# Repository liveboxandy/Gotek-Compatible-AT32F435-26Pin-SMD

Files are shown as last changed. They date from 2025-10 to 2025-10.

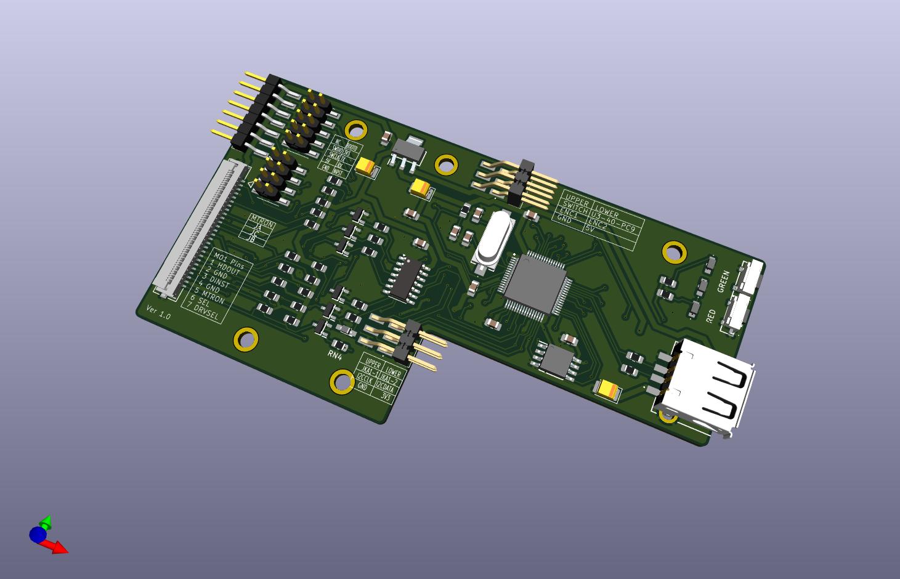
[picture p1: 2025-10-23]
Gotek.jpg

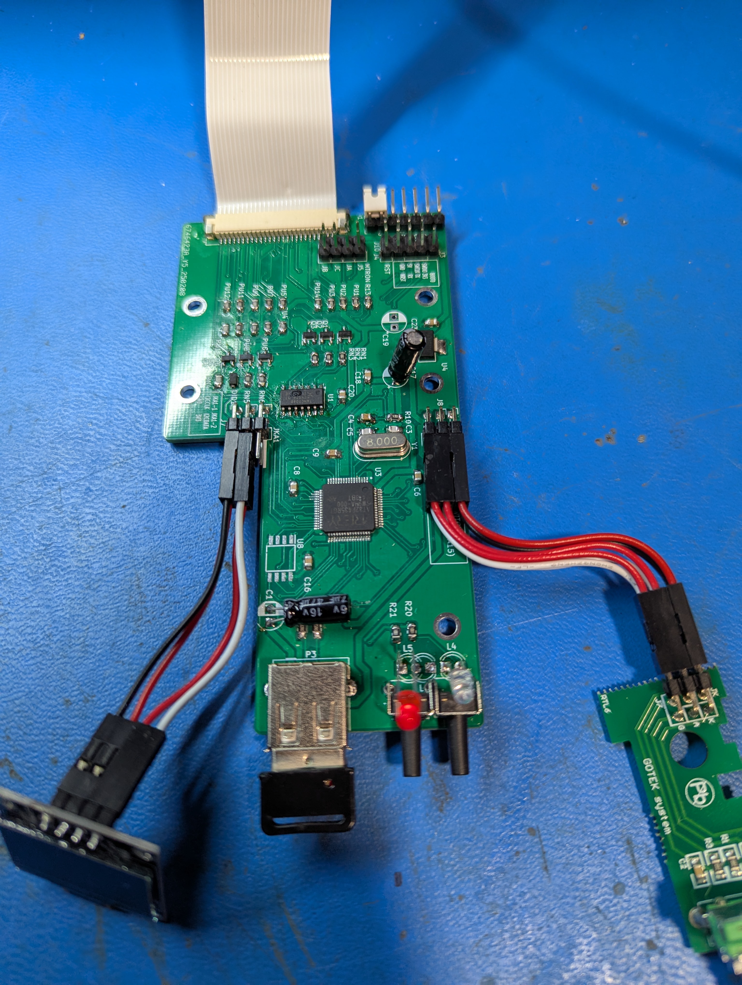
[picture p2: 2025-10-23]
Pictures/AT32F435RGT7.jpg

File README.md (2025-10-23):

Initial schematic and gerbers for a Gotek(?) compatible with an Artery AT32F435RGT7 chip and a 26 Pin FFC connector using SMD components.

Used SFRKC30.AT4.35 PCB for most of the schematic and layout but used SFRC2D.B PCB for the 26 Pin FFC connections.

Used photographs and a multimeter along with removing U1 and U3 on the SFRKC30.AT4.35 to get to the traces underneath.

Where possible I followed the original PCB routing of the SFRKC30.AT4.35 but Kicad has some different rules for trace widths (between pins 5&6 of U8, which isn't fitted for FlashFloppy).

Using SMD components required a few more routing changes but electrically it is still good. What a pain in the ass to find SMD parts that don't cost a fortune and have Kicad mod and sym files.

Restructured folders

Added all non pop components so that ibom displays everthing

Added ibon (bom.ibom.html)

U8 not fitted for use with FlashFloppy.

LEDS 3 & 5 are not normally fitted

Works as a replacement for the floppy in a TDS3052 Oscilloscope. Just needs a very slim case (13mm)

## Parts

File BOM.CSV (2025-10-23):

Reference | Value | Datasheet | Footprint | Qty | DNP
C1,C17,C19 | 47uF | ~ | Capacitor_Tantalum_SMD:CP_EIA-3528-21_Kemet-B_Pad1.50x2.35mm_HandSolder | 3
C3,C5 | 22pF | ~ | Capacitor_SMD:C_0805_2012Metric_Pad1.18x1.45mm_HandSolder | 2
C4,C6,C8,C9,C16,C18,C20,C23 | 100nF | ~ | Capacitor_SMD:C_0805_2012Metric_Pad1.18x1.45mm_HandSolder | 8
DID1 | 1N4148WS | https://www.vishay.com/docs/85751/1n4148ws.pdf | Gotek:SODFL2512X90N | 1
J1 | TSM-107-01-L-SH | http://suddendocs.samtec.com/prints/tsm-1xx-xx-xxx-xx-x-xxx-x-mkt.pdf | Gotek:TSM-107-01-L-SH | 1
J4 | TSM-105-04-S-DV | https://componentsearchengine.com/Datasheets/1/TSM-105-04-S-DV.pdf | Gotek:TSM-105-04-S-DV | 1
J5 | TSM-104-04-S-DV | http://suddendocs.samtec.com/prints/tsm-1xx-xx-xxx-xx-x-xxx-x-mkt.pdf | Gotek:TSM-104-04-S-DV | 1
J7,J8 | TSM-103-01-L-DH-TR | http://suddendocs.samtec.com/prints/tsm-1xx-xx-xxx-xx-xx-xxx-xx-mkt1.pdf | Gotek:TSM-103-01-L-DH-TR | 2
L3,L4 | LED GREEN | ~ | Gotek:APT2012PGW | 2
L5 | LED RED | https://docs.broadcom.com/doc/AV02-0975EN | Gotek:HSMCC177 | 1
P1 | 2005280260 | 2005280260 | Gotek:MOLEX_CON_2005280260 | 1
P3 | USB_A | https://gct.co/files/drawings/usb1046.pdf?v=ccb5d20d-0631-4297-aa3c-9c34fccf9fbc | Gotek:USB1046GF0190LBA | 1
PU1,PU2,PU3,PU4,PU5,PU6,PU7,PU8,PU9,PU10,PU11,PU12,PU13,PU14,R20,RN1,RN2,RN3,RN4,RN5,RN6 | 1K | ~ | Resistor_SMD:R_0805_2012Metric_Pad1.20x1.40mm_HandSolder | 21
Q1,Q2,Q3,Q4,Q5,Q6 | PMBT2222A,215 | https://assets.nexperia.com/documents/data-sheet/PMBT2222A.pdf | Gotek:SOT95P280X130-3N | 6
R1,R2 | 22R | ~ | Resistor_SMD:R_0805_2012Metric_Pad1.20x1.40mm_HandSolder | 2
R10,R13 | 4K7 | ~ | Resistor_SMD:R_0805_2012Metric_Pad1.20x1.40mm_HandSolder | 2
R21 | 12K | ~ | Resistor_SMD:R_0805_2012Metric_Pad1.20x1.40mm_HandSolder | 1
S3,S4 | 1188E-1K2-V-T_R | http://www.dip.com.tw/en/en-product-information/en-switch004/item/2445-1188?highlight=WzExODhd | Gotek:1188E1K2VTR | 2
U1 | 74AHC04 | https://assets.nexperia.com/documents/data-sheet/74AHC_AHCT04.pdf | Package_SO:SO-14_3.9x8.65mm_P1.27mm | 1
U3 | AT32F435RGT7 |  | Gotek:QFP50P1200X1200X160-64N | 1
U4 | AMS1117-3.3 | http://www.advanced-monolithic.com/pdf/ds1117.pdf | Gotek:SOT229P700X180-4N | 1
U8 | SST25VF016B-50-4C-S2AF | https://ww1.microchip.com/downloads/en/DeviceDoc/20005044C.pdf | Gotek:SOIC127P790X216-8N | 1
Y1 | 8Mhz | https://componentsearchengine.com/Datasheets/1/LFXTAL050985Bulk.pdf | Gotek:LFXTAL050985Bulk | 1

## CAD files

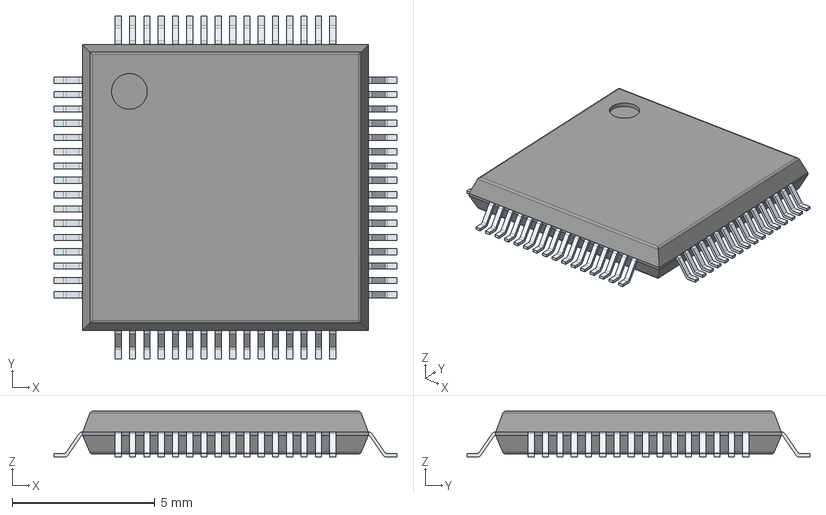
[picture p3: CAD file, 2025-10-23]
STP/AT32F415RxT7.stp
12.0 x 12.0 x 1.60 mm
PinsArrayLR
PinsArrayTB

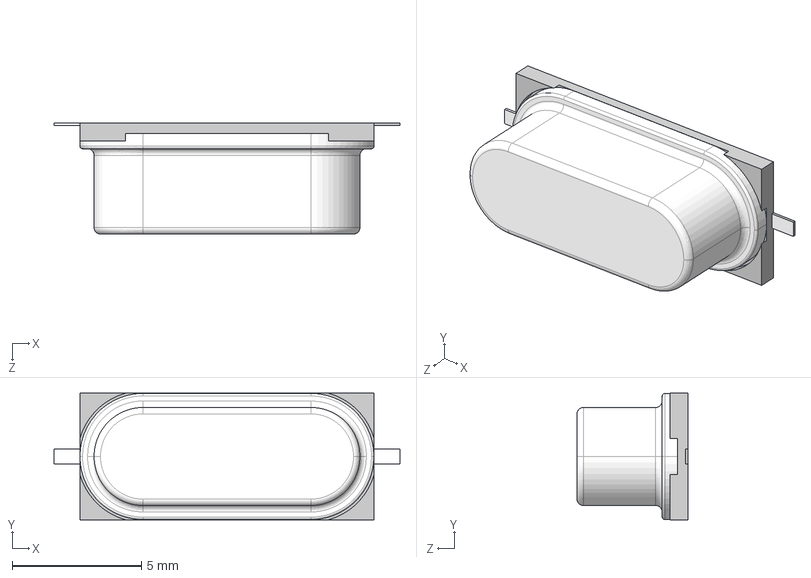
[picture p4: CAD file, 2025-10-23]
STP/LFXTAL050985Bulk.stp
13.4 x 4.90 x 4.30 mm

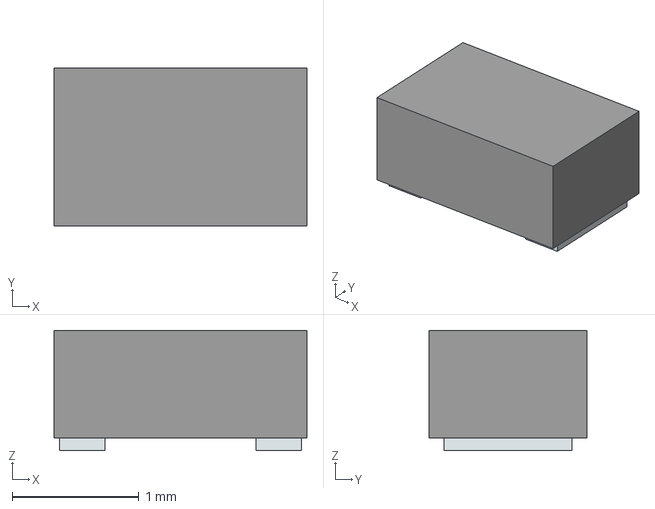
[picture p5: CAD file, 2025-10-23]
STP/APT2012PGW.stp
2.00 x 1.25 x 0.95 mm
Pins

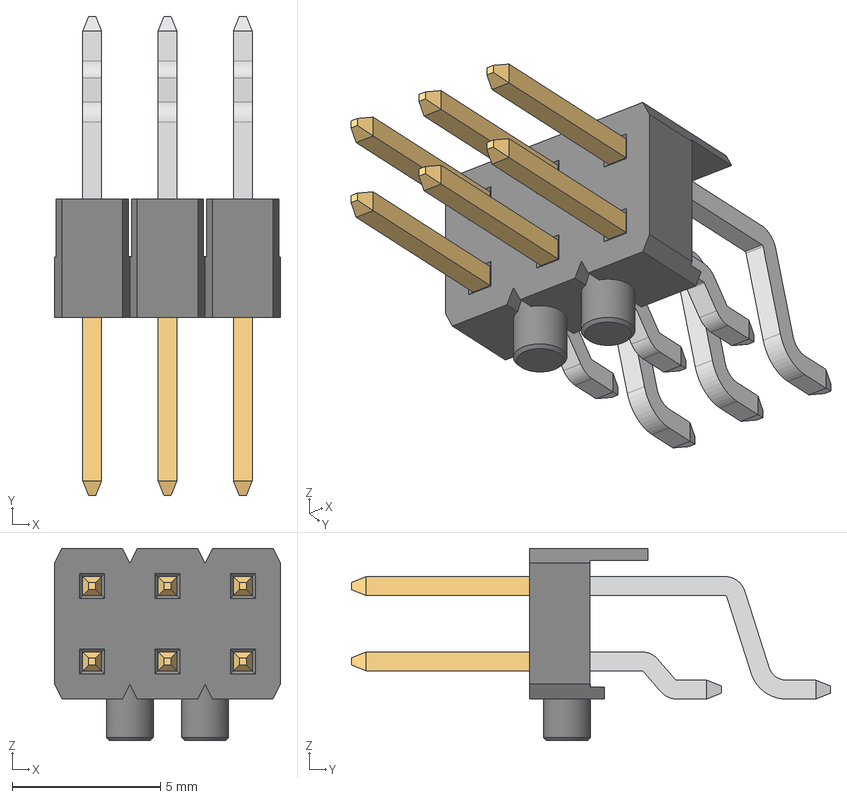
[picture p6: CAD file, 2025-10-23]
STP/6101XX249121_610106249121.step
7.62 x 16.2 x 6.48 mm
6100xx249121_PIN LONGUE x 3
6100xx249121_PIN COURTE x 3

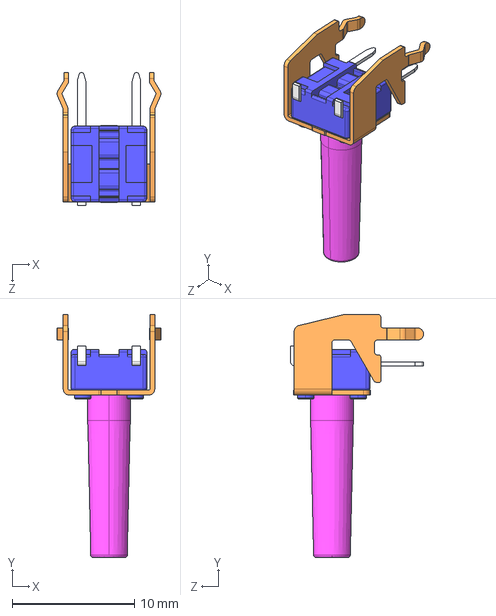
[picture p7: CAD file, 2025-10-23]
STP/SKHHNH.stp
8.50 x 19.9 x 10.9 mm

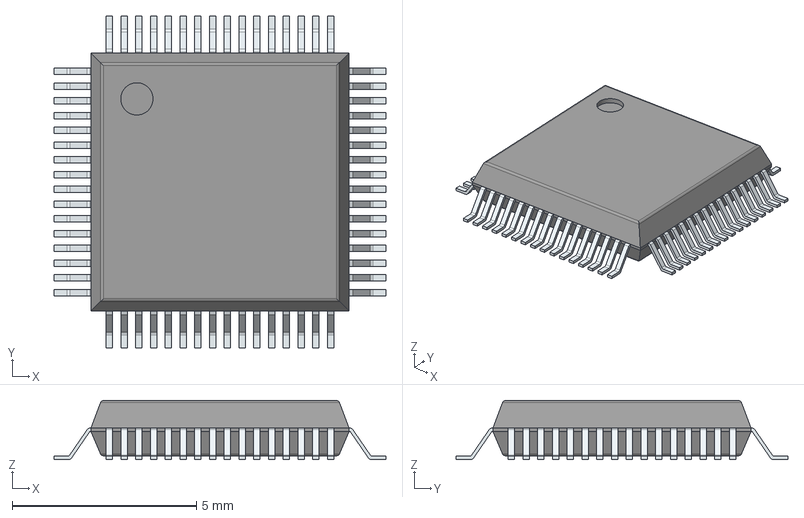
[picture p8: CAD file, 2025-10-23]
STP/at32f415rct7.stp
9.00 x 9.00 x 1.60 mm
PinsArrayLR
PinsArrayTB

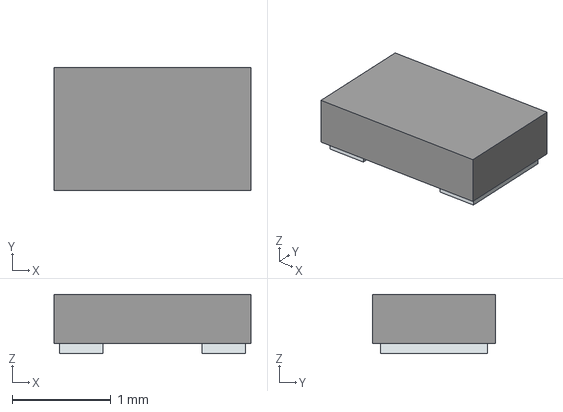
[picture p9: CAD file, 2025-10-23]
STP/HSMC-C177.stp
2.00 x 1.25 x 0.6 mm
Pins

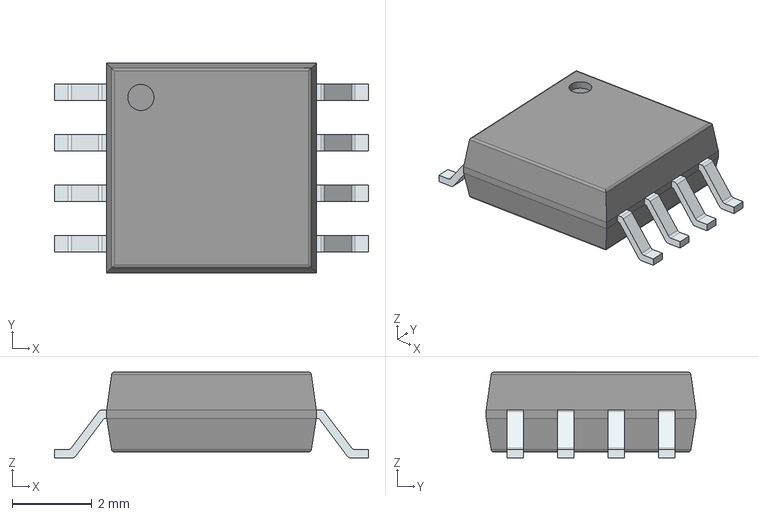
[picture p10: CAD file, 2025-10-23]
STP/SST25VF016B-50-4C-S2AF.stp
7.90 x 5.28 x 2.16 mm
PinsArrayLR

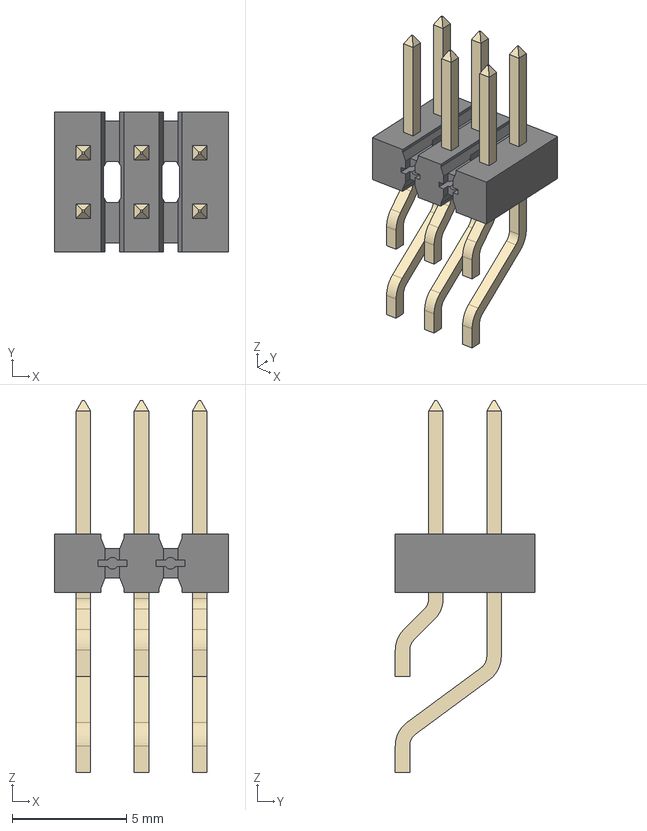
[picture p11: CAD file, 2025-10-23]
STP/TSM-103-01-L-DH-TR.stp
7.62 x 6.10 x 16.3 mm

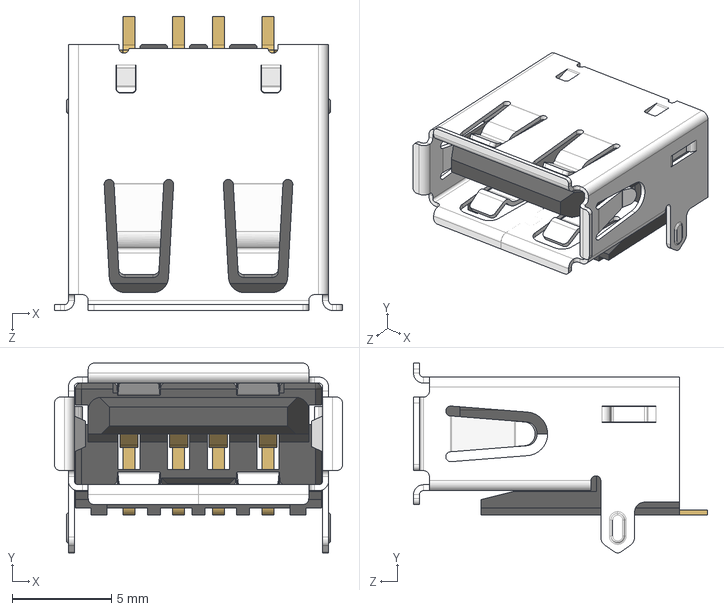
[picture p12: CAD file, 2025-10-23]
STP/USB1046-GF-0190-L-B-A.stp
14.5 x 9.55 x 14.8 mm

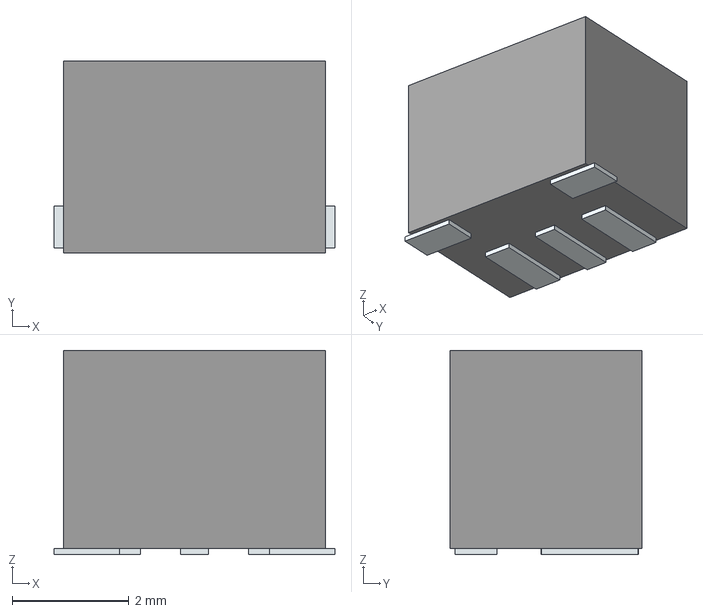
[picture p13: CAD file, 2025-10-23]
STP/SKRTLBE010.stp
4.82 x 3.30 x 3.50 mm
Pins

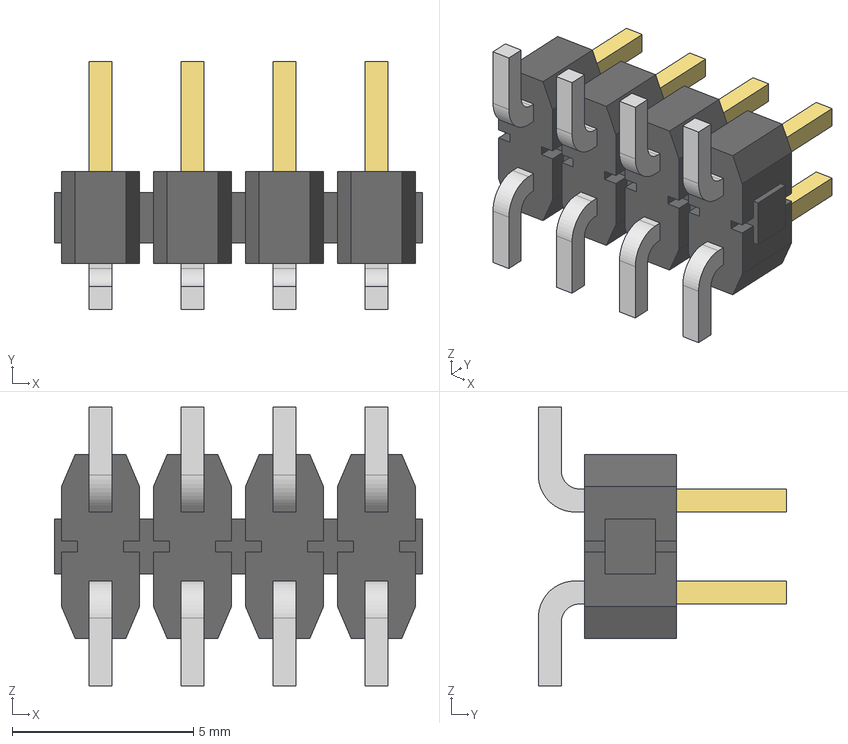
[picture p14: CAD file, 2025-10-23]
STP/TSM-104-04-S-DV.stp
10.2 x 6.86 x 7.70 mm
TSM-104-04-DV_body
T-1S6-21-S(-04-4-DV)
T-1S6-21-S(-04-4-DV)2

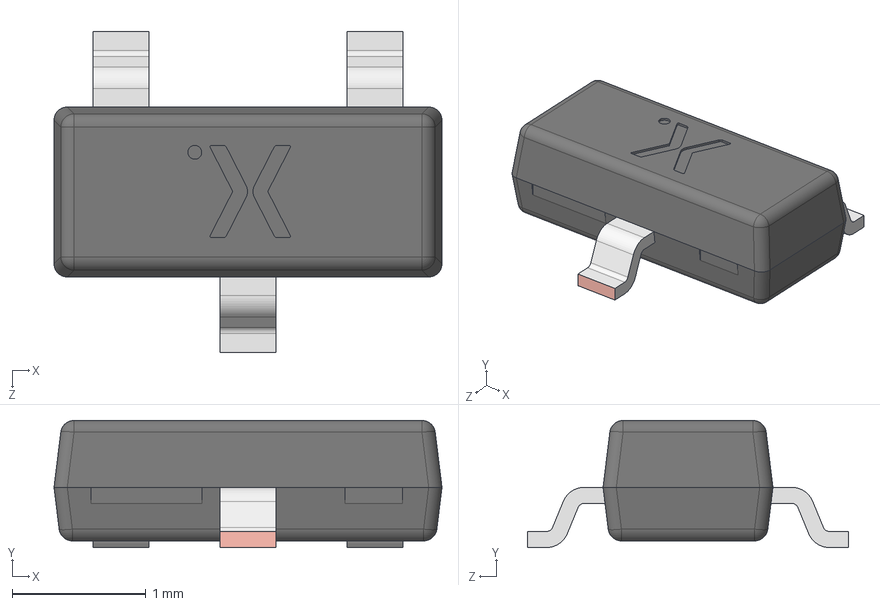
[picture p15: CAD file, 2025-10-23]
STP/PMBT2222A,215.stp
2.90 x 0.95 x 2.40 mm
SOT23 lower body
SOT23 Lead x 3
SOT23 Upper body

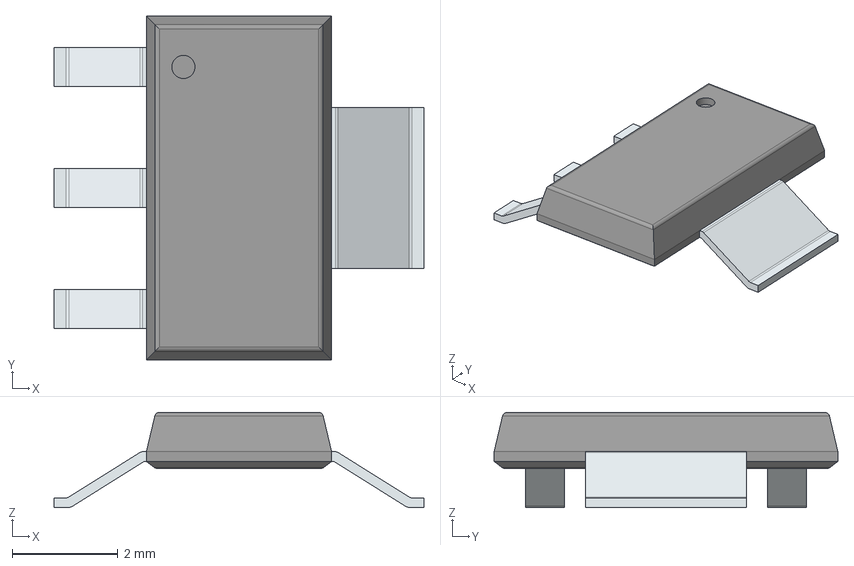
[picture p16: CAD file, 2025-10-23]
STP/ams1117-3.3v.stp
7.00 x 6.50 x 1.80 mm
PinsArrayL
FilletPinR

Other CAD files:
STP/SKHHNK.STEP
STP/SKHHNHA010.stp
STP/1188E-1K2-V-T_R.stp
STP/171826-4.stp
STP/1N4148WS.stp
STP/ABL-8.000MHZ-B2.stp
STP/M20-8750442.stp
STP/M20-8760442P.stp
STP/M20-8760542P.stp
STP/M20-8890245R.stp
STP/M20-8890345R.stp
STP/M20-8900705.stp
STP/Molex 2005280260.stp
STP/SKHHNK.stp
STP/SKRTLAE010.stp
STP/TSM-105-04-S-DV.stp
STP/TSM-107-01-L-SH.stp
STP/USB1055-GF-L-A.stp

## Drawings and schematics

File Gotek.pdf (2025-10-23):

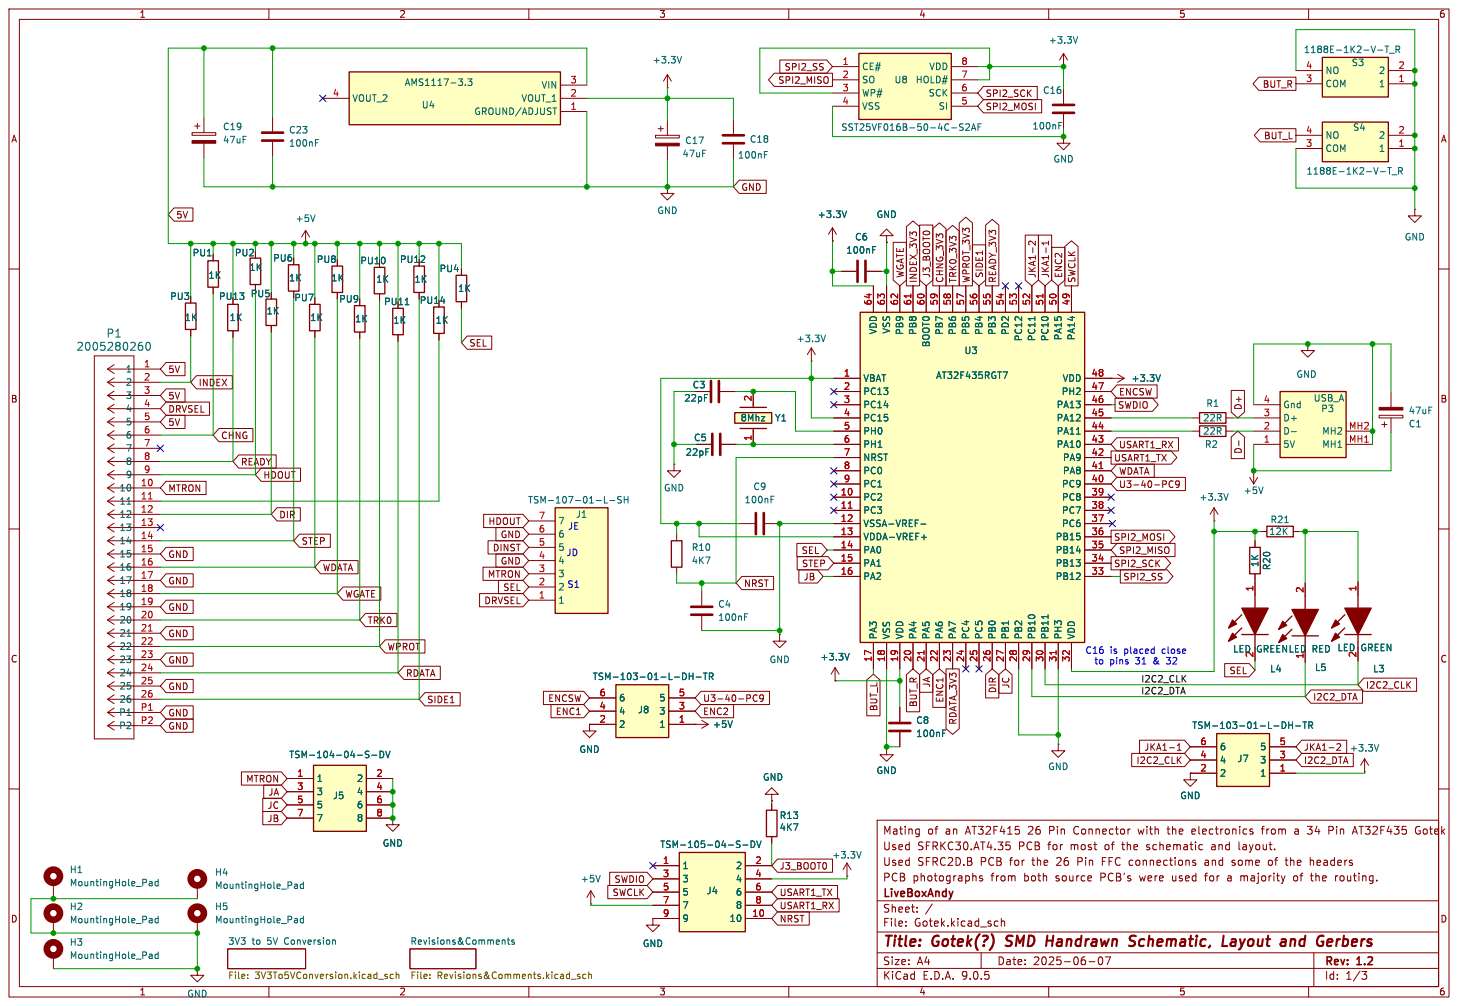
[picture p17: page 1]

I2C2_DTA HDOUT DINST GND MTRON

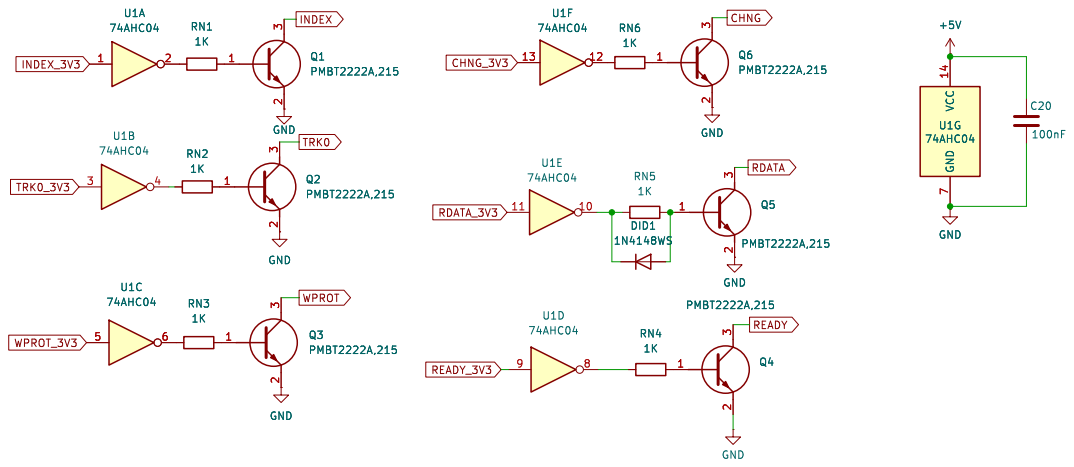
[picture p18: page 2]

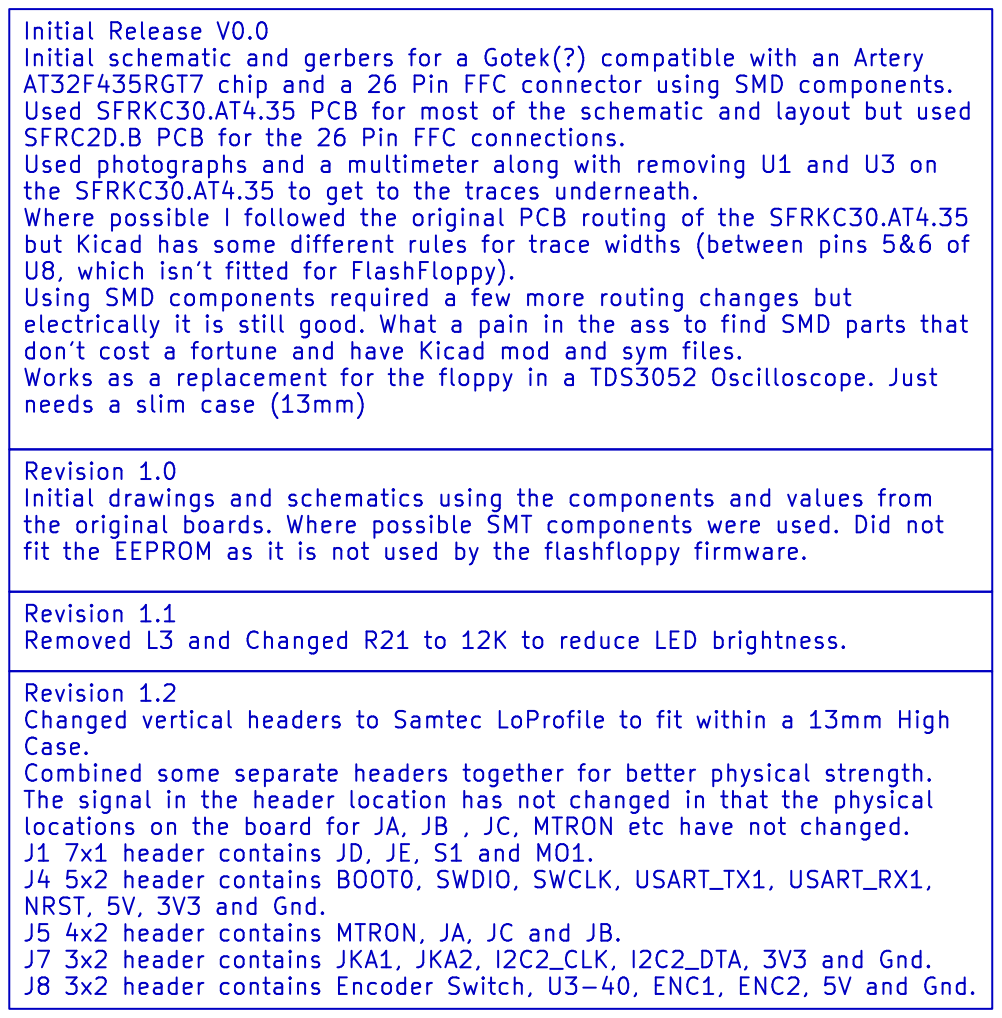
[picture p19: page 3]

Revision 1.1 Removed L3 and Changed R21 to 12K to reduce LED brightness. Revision 1.0

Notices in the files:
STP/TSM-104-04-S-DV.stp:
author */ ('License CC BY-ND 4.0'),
